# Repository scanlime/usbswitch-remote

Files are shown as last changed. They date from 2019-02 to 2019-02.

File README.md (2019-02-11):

# usbswitch-remote

Replacement firmware and optional wired remote for UGREEN brand USB 2.0 sharing switch.

I've tested this on a version of the switch from 2017 which had five USB type A sockets,
and the button was in one corner. Newer versions of the same product appear to have
four Type B and one Type A, which no longer violates the USB spec, and the button is
in the center. I'm not sure if those units use compatible firmware.

This device is effectively a high-speed analog multiplexer, based on a tree of
three [SV7030 USB 2.0 switch](http://product.savitech-ic.com/DataSheet/SV7030DS-REV095a.pdf)
chips controlled by an [STM8S003F3 microcontroller](https://www.st.com/resource/en/datasheet/stm8s003k3.pdf).

## Firmware

The STM8 is a low-cost 8-bit micro with 8kB of flash memory, and there's an available PCB footprint
for an STLink or compatible debug interface.

There is no GCC or LLVM port, but we can tolerate [SDCC](http://sdcc.sourceforge.net/) for a small project like this!

The included firmware is written in C for the bare metal, no vendor libraries are needed.
It supports switching channels using the built-in button or an optional wired remote.
The original firmware had quite bad button debouncing, which is fixed. I've also omitted
support for automatic switching with voltage sensing. It could be added, but I didn't want
the feature as I found it distracting.

* Build the firmware with [SDCC](http://sdcc.sourceforge.net/) (optional).
* Install it with either [OpenOCD](http://openocd.org/) or [stm8flash](https://github.com/vdudouyt/stm8flash)

## Remote

To have direct control over switching to each of the four channels, a simple wired
remote with four lighted buttons can be added using an audio cable and some passive
components. See the included schematic. It uses a variant of charlieplexing that drives
four LEDs as usual, then splits the two remaining currents paths into two buttons each,
using an RC circuit to disambiguate them. If this needs a name, I'm calling it Tucoplexing
after my cat Tuco! 😸

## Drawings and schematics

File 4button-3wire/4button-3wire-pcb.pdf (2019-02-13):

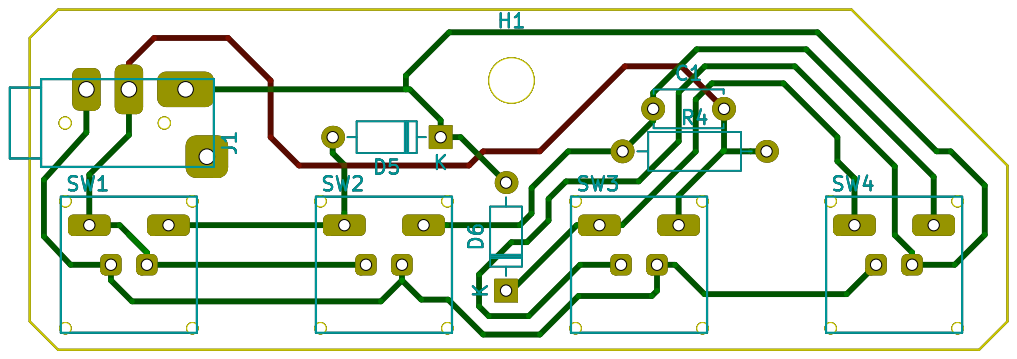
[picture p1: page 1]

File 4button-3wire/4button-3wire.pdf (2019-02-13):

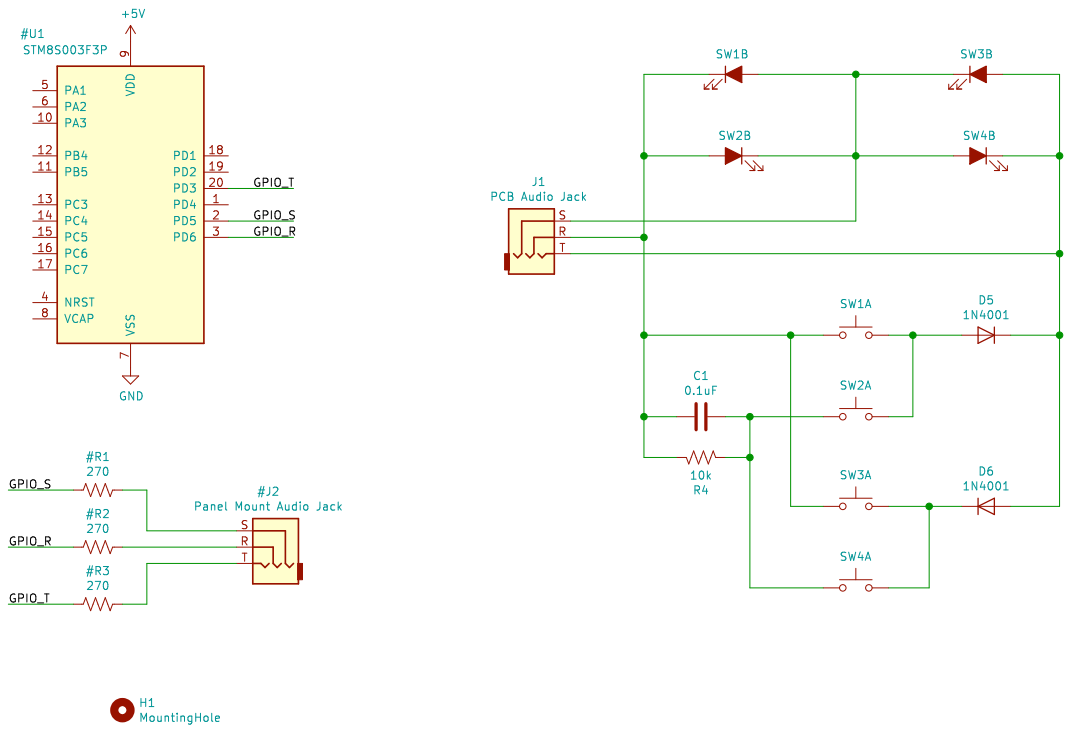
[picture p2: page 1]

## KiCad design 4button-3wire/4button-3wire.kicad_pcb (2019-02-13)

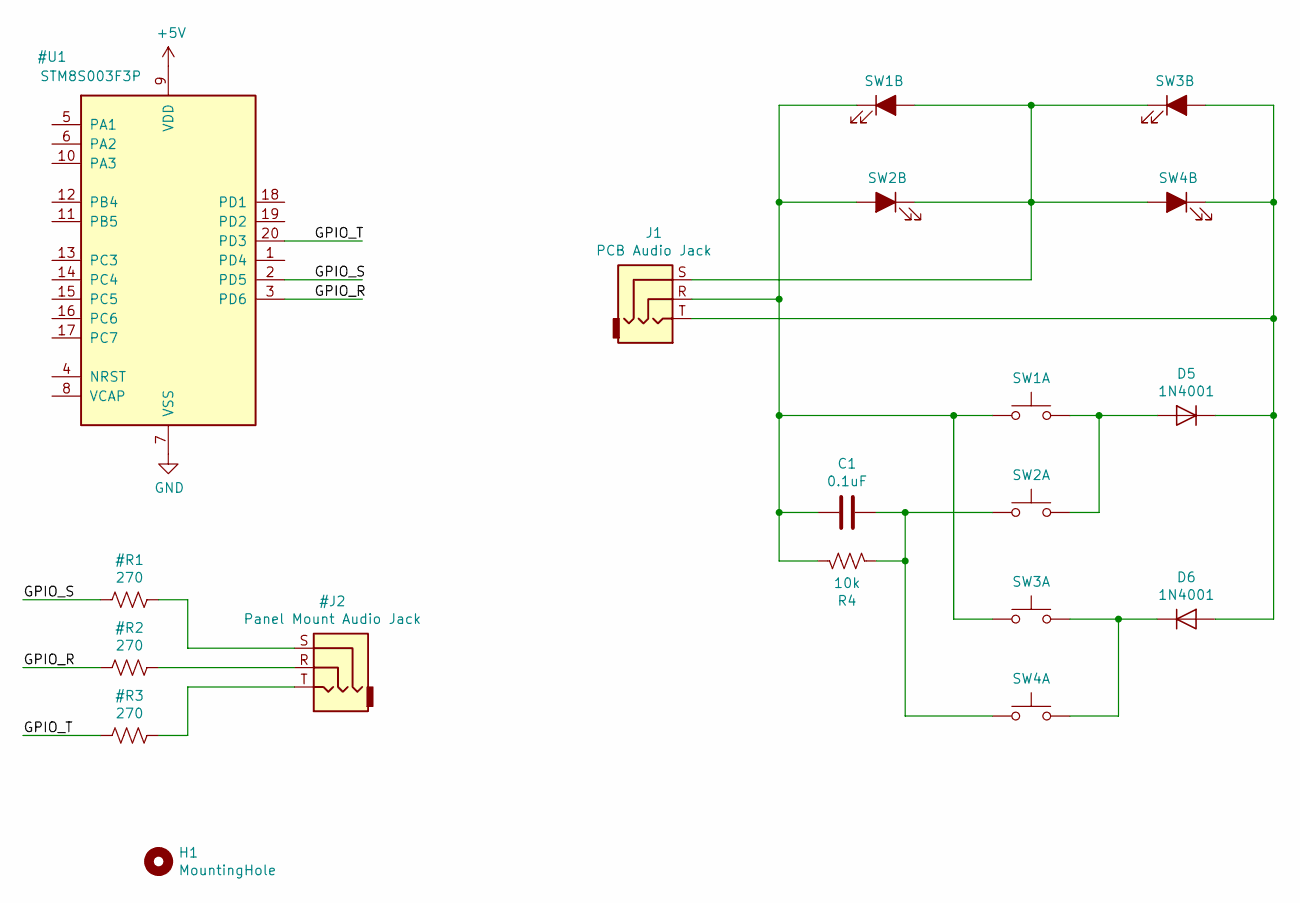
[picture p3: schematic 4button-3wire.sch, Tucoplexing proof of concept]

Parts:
C1: 0.1uF; C_Disc_D4.7mm_W2.5mm_P5.00mm
D5, D6: 1N4001; D_DO-35_SOD27_P7.62mm_Horizontal
H1: MountingHole; MountingHole_3.2mm_M3
J1: PCB Audio Jack; Jack_3.5mm_7mmSpacing
R4: 10k; R_Axial_DIN0207_L6.3mm_D2.5mm_P10.16mm_Horizontal
SW1, SW2, SW3, SW4: SW_Push_LED_Separate; SW_LightedPush_ITW_Series39_SmallPads

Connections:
unnamed: C1.1, R4.1, SW2.2, SW4.2
unnamed: C1.2, J1.R, R4.2, SW1.1, SW1.3 (K), SW2.4 (A), SW3.2
unnamed: D5.1 (K), D6.2 (A), J1.T, SW3.4 (A), SW4.3 (K)
unnamed: D5.2 (A), SW1.2, SW2.1
unnamed: D6.1 (K), SW3.1, SW4.1
unnamed: J1.S, SW1.4 (A), SW2.3 (K), SW3.3 (K), SW4.4 (A)

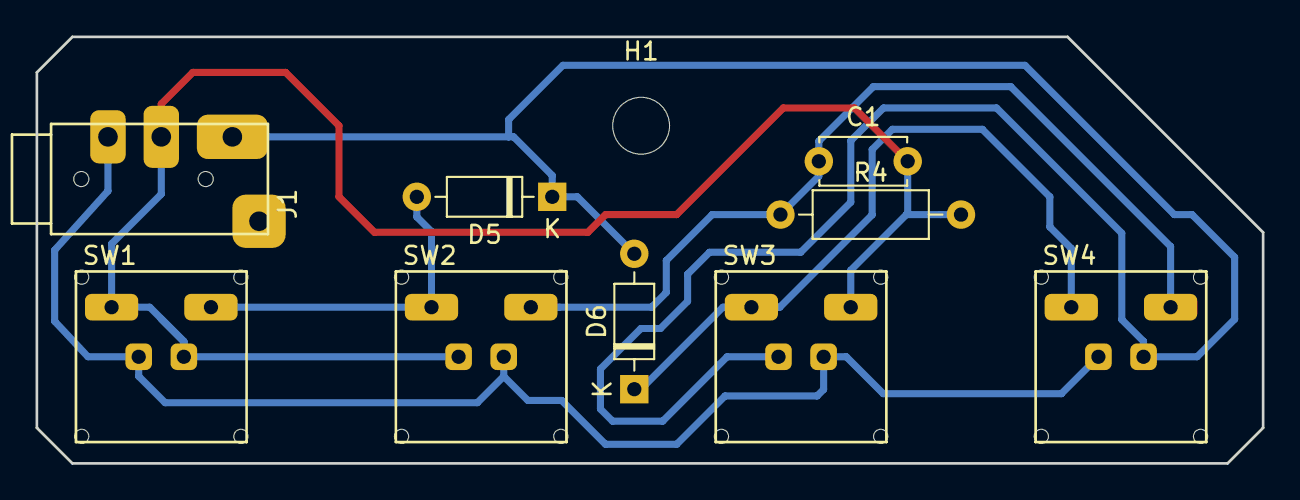
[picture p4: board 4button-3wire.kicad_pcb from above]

Board: 2 copper layers, 69.0 x 24.0 mm, 10 parts (0 on the bottom side), 6 nets.

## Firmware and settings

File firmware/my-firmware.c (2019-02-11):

#include <stdint.h>
#include <stdbool.h>

struct gpio {
    uint8_t odr, idr, ddr, cr1, cr2;
};

typedef volatile struct gpio* gpio_t;

#define GPIO_A  ((gpio_t)0x5000)
#define GPIO_B  ((gpio_t)0x5005)
#define GPIO_C  ((gpio_t)0x500a)
#define GPIO_D  ((gpio_t)0x500f)

#define PIN_LED1        GPIO_C, (1U<<7)
#define PIN_LED2        GPIO_C, (1U<<6)
#define PIN_LED3        GPIO_C, (1U<<5)
#define PIN_LED4        GPIO_C, (1U<<4)

#define PIN_SEL_01      GPIO_B, (1U<<4)     // Used for 0 and 1
#define PIN_SEL_23      GPIO_B, (1U<<5)     // Used for 2 and 3
#define PIN_SEL_MSB     GPIO_D, (1U<<2)     // Select between 01 / 23

#define PIN_TUCOPLEX_S  GPIO_D, (1U<<5)     // Sleeve, via 270 ohm
#define PIN_TUCOPLEX_R  GPIO_C, (1U<<3)     // Ring, via 270 ohm
#define PIN_TUCOPLEX_T  GPIO_D, (1U<<3)     // Tip, via 270 ohm

#define PIN_SENSE1      GPIO_A, (1U<<1)
#define PIN_SENSE2      GPIO_A, (1U<<2)
#define PIN_SENSE3      GPIO_D, (1U<<4)
#define PIN_SENSE4      GPIO_A, (1U<<3)

#define PIN_BUTTON      GPIO_D, (1U<<6)

static void led_delay()
{
    // Arbitrary time to display LED, about 15ms
    for (uint8_t j = 20; j; j--)
        for (uint8_t k = 255; k; k--)
            __asm__ ("nop");
}

static void charge_delay()
{
    // About 8ms, plenty of time to charge the RC circuit in a button
    for (uint8_t j = 10; j; j--)
        for (uint8_t k = 255; k; k--)
            __asm__ ("nop");
}

static void input_pullup_delay()
{
    // Small delay for charging weak pull-up
    for (uint8_t k = 5; k; k--)
            __asm__ ("nop");
}

static inline void gpio_mode_push_pull(gpio_t port, uint8_t pin)
{
    port->ddr |= pin;
    port->cr1 |= pin;
    port->cr2 &= ~pin;
}

static inline void gpio_mode_float(gpio_t port, uint8_t pin)
{
    port->ddr &= ~pin;
    port->cr1 &= ~pin;
    port->cr2 &= ~pin;
}

static inline void gpio_mode_pull_up(gpio_t port, uint8_t pin)
{
    port->ddr &= ~pin;
    port->cr1 |= pin;
    port->cr2 &= ~pin;    
}

static inline void gpio_output(gpio_t port, uint8_t pin, bool value)
{
    if (value)
        port->odr |= pin;
    else
        port->odr &= ~pin;
}

static inline bool gpio_input(gpio_t port, uint8_t pin)
{
    return (port->idr & pin) != 0;
}

void gpio_init()
{
    gpio_mode_push_pull(PIN_LED1);
    gpio_mode_push_pull(PIN_LED2);
    gpio_mode_push_pull(PIN_LED3);
    gpio_mode_push_pull(PIN_LED4);
    gpio_mode_push_pull(PIN_SEL_01);
    gpio_mode_push_pull(PIN_SEL_23);
    gpio_mode_push_pull(PIN_SEL_MSB);
    gpio_mode_pull_up(PIN_BUTTON);
    gpio_mode_float(PIN_TUCOPLEX_S);
    gpio_mode_float(PIN_TUCOPLEX_R);
    gpio_mode_float(PIN_TUCOPLEX_T);
}

void led_set_channel(uint8_t ch)
{
    gpio_output(PIN_LED1, ch != 0);
    gpio_output(PIN_LED2, ch != 1);
    gpio_output(PIN_LED3, ch != 2);
    gpio_output(PIN_LED4, ch != 3);
}

void usb_set_channel(uint8_t ch)
{
    gpio_output(PIN_SEL_01, ch & 1);
    gpio_output(PIN_SEL_23, ch & 1);
    gpio_output(PIN_SEL_MSB, ch >> 1);
}

void set_channel(uint8_t ch)
{
    led_set_channel(ch);
    usb_set_channel(ch);
}

void scan_one_led(gpio_t cathode_port, uint8_t cathode_pin,
                  gpio_t anode_port, uint8_t anode_pin)
{
    gpio_output(cathode_port, cathode_pin, false);
    gpio_output(anode_port, anode_pin, true);
    gpio_mode_push_pull(cathode_port, cathode_pin);
    gpio_mode_push_pull(anode_port, anode_pin);

    led_delay();

    gpio_mode_float(cathode_port, cathode_pin);
    gpio_mode_float(anode_port, anode_pin);
}

void scan_led_for_channel(uint8_t ch)
{
    switch (ch) {
        case 0:
            scan_one_led(PIN_TUCOPLEX_R, PIN_TUCOPLEX_S);
            break;
        case 1:
            scan_one_led(PIN_TUCOPLEX_S, PIN_TUCOPLEX_R);
            break;
        case 2:
            scan_one_led(PIN_TUCOPLEX_S, PIN_TUCOPLEX_T);
            break;
        case 3:
            scan_one_led(PIN_TUCOPLEX_T, PIN_TUCOPLEX_S);
            break;
    }
}

uint8_t scan_button_path(gpio_t cathode_port, uint8_t cathode_pin,
                         gpio_t anode_port, uint8_t anode_pin)
{
    uint8_t result = 0;

    gpio_output(cathode_port, cathode_pin, false);
    gpio_output(anode_port, anode_pin, true);
    gpio_mode_push_pull(cathode_port, cathode_pin);

    gpio_mode_pull_up(anode_port, anode_pin);
    input_pullup_delay();

    // Sample state without any pre-charge time
    if (!gpio_input(anode_port, anode_pin)) {

        // Seems like at least one of the two buttons on this
        // path are pressed; try charging the capacitor and sampling
        // again, to tell the two states apart.

        // Charge capacitor and sample again
        gpio_mode_push_pull(anode_port, anode_pin);
        charge_delay();

        gpio_mode_pull_up(anode_port, anode_pin);
        input_pullup_delay();

        // If shorted button, this is still low and we return 1.
        // If it's the one with an RC circuit, it's charged by now and
        // we return 2.
        result = 1 + gpio_input(anode_port, anode_pin);
    }

    gpio_mode_float(cathode_port, cathode_pin);
    gpio_mode_float(anode_port, anode_pin);

    return result;
}

uint8_t scan_buttons_once()
{
    uint8_t result;

    result = scan_button_path(PIN_TUCOPLEX_T, PIN_TUCOPLEX_R);
    if (result)
        return result;

    result = scan_button_path(PIN_TUCOPLEX_R, PIN_TUCOPLEX_T);
    if (result)
        return result + 2;

    if (!gpio_input(PIN_BUTTON)) {
        return 5;
    }

    return 0;
}

void main()
{
    uint8_t channel = 0;
    uint8_t button_now = 0;
    uint8_t button_debounce = 0;
    uint8_t button_prev = 0;

    gpio_init();

    while (1) {
        set_channel(channel);
        scan_led_for_channel(channel);
        button_now = scan_buttons_once();

        if (button_now == button_debounce) {

            if (button_now && button_now <= 4) {
                // Set channel
                channel = button_now - 1;
            }
            else if (button_now == 5 && button_prev == 0) {
                // Next channel
                channel = (channel + 1) & 3;
            }

            button_prev = button_now;
        }
        button_debounce = button_now;
    }
}

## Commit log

2019-02-11 Initial working version
    [4button-3wire.kicad_pcb, 4button-3wire.sch]
2019-02-11 Include schematic PDF
2019-02-11 Update title block
    [4button-3wire.sch]
2019-02-11 Share the RC circuit between both button pairs
    [4button-3wire.sch]
2019-02-12 Mostly routed
    [4button-3wire.kicad_pcb, 4button-3wire.sch]
2019-02-12 Trying to make single layer
    Moved some components around
    Made switch pads a little smaller
    Moved top board edge up
    [_saved_4button-3wire.sch]
2019-02-12 Changed Switch Footprint
    Made a new footprint with smaller size pads
    [4button-3wire.sch, _saved_4button-3wire.sch]
2019-02-13 First milled PCB revision
    [4button-3wire-B.Cu.gbr, 4button-3wire-B.Mask.gbr, 4button-3wire-B.Paste.gbr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]
2019-02-17 Mechanical prototype
